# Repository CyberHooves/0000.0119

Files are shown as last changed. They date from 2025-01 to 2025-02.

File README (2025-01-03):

HAOS REDRO PN: 0000.0109

Description:
============

This is a configurable single-phase PFC booster for up to 1.2kW loads, intended for use as a front end to switchmode power supplies. The output voltage is 400V DC. An auxiliary 12V supply referenced to the negative (400V return) output is provided for powering downstream converters. This module is designed with a 35mm vertical profile to be installed within 1U rack-mounting cases.

An open-collector "power good" output is provided to indicate that the booster is switching. This should be used to disable the connected load(s) should the booster stop switching, as this will likely be due to a fault condition.
An active-low enable input is provided to disable the PFC booster in applications that require a standby mode.

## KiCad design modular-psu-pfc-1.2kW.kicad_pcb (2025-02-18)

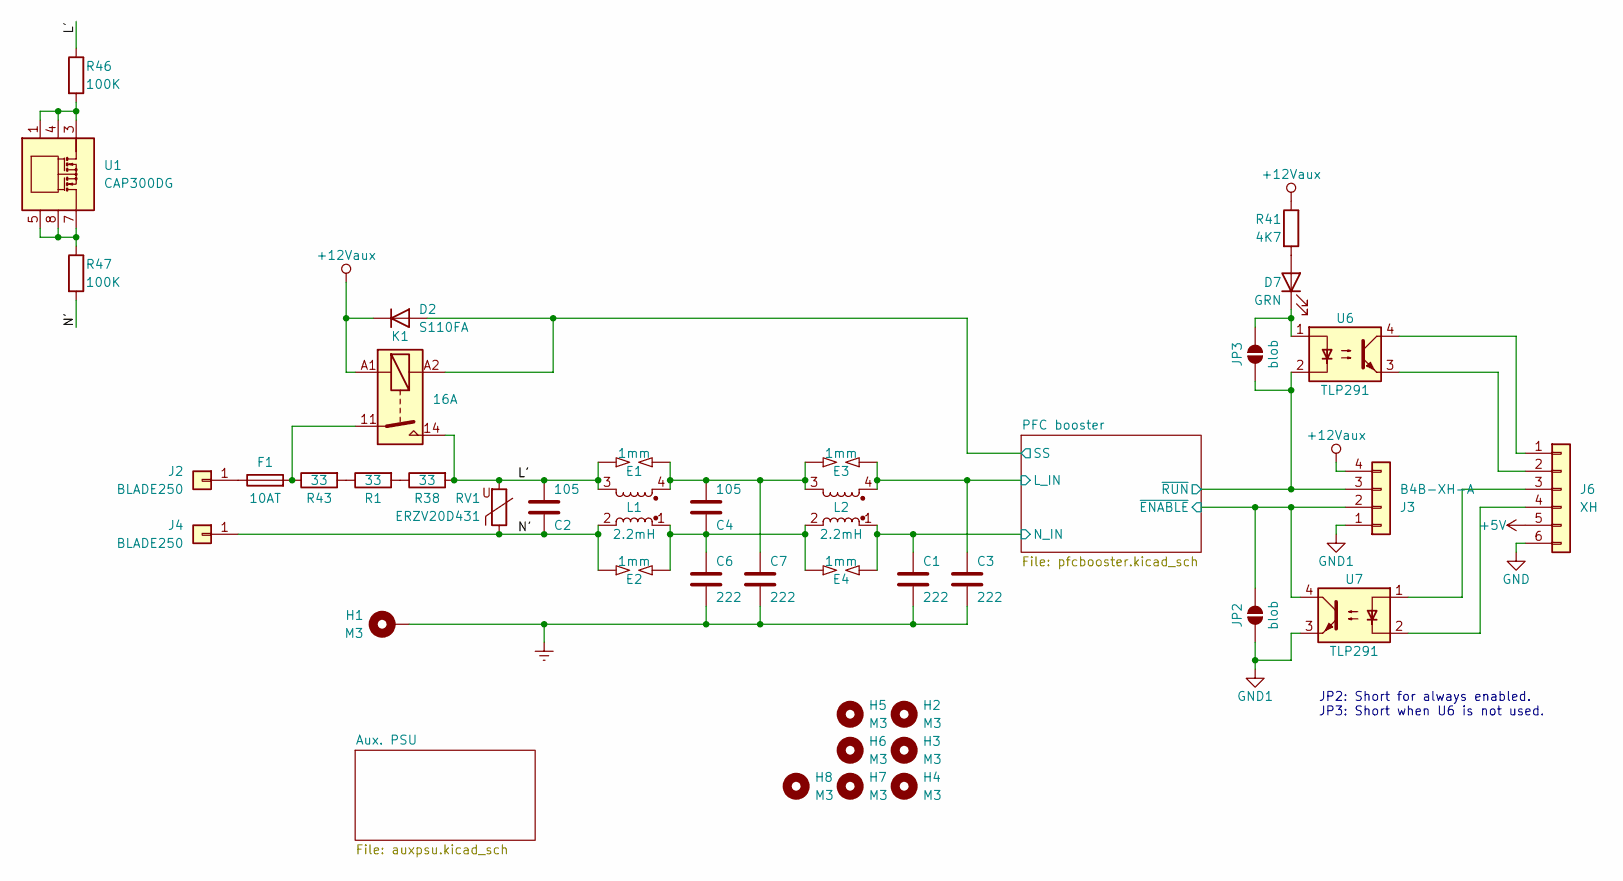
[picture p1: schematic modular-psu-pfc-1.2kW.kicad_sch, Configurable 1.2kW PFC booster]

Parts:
C1, C3, C6, C7: 222; C_Disc_D10.5mm_W5.0mm_P10.00mm
C2, C4: 105; C_Rect_L26.5mm_W11.5mm_P22.50mm_MKS4
D2: S110FA; D_SOD-123
D7: GRN; LED_D3.0mm_Clear
E1, E2, E3, E4: 1mm; SG_6MM_3SPIKE_GAP1MM
F1: 10AT; Fuseholder_Clip-6.3x32mm_Littelfuse_102071_Inline_P34.70x7.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
H1: M3; MountingHole_3.2mm_M3_Pad
H2, H3, H4, H5, H6, H7, H8: M3; MountingHole_3.2mm_M3
J2, J4: BLADE250; CON-BLADE250-VERTICAL
J3: B4B-XH-A; JST_XH_B4B-XH-AM_1x04_P2.50mm_Vertical
J6: XH; JST_XH_B6B-XH-AM_1x06_P2.50mm_Vertical
JP2, JP3: blob; SolderJumper-2_P1.3mm_Open_RoundedPad1.0x1.5mm
K1: 16A; Relay_SPST_Schrack-RT1-16A-FormA_RM5mm
L1, L2: 2.2mH; L_CommonMode_Toroid_Vertical_L30.5mm_W15.2mm_Px10.16mm_Py20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
R1, R38, R43: 33; R_Axial_DIN0617_L17.0mm_D6.0mm_P5.08mm_Vertical
R41: 4K7; R_0805_2012Metric
R46, R47: 100K; R_1210_3225Metric
RV1: ERZV20D431; RV_Disc_D21.5mm_W4.7mm_P10mm
U1: CAP300DG; SOIC-8_3.9x4.9mm_P1.27mm
U6, U7: TLP291; SOP-4_7.5x4.1mm_P2.54mm

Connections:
+5V: J6.5; also elsewhere on the board
+12Vaux: D2.1 (K), J3.4, K1.A1, R41.1; also elsewhere on the board
/L': C2.2, E1.1, K1.14, L1.3, R38.2, R46.1, RV1.2
/N': C2.1, E2.1, J4.1, L1.2, R47.2, RV1.1
/PFC booster/L_IN: C3.1, E3.2, L2.4; also elsewhere on the board
/PFC booster/N_IN: C1.1, E4.2, L2.1; also elsewhere on the board
/PFC booster/SS: D2.2 (A), K1.A2; also elsewhere on the board
/PFC booster/~ENABLE: J3.2, JP2.2 (B), U7.4; also elsewhere on the board
/PFC booster/~RUN: J3.3, JP3.1 (A), U6.2; also elsewhere on the board
Earth: C1.2, C3.2, C6.2, C7.2, H1.1
GND: J6.6; also elsewhere on the board
GND1: J3.1, JP2.1 (A), U7.3; also elsewhere on the board
unnamed: C4.1, C6.1, E2.2, E4.1, L1.1, L2.2
unnamed: C4.2, C7.1, E1.2, E3.1, L1.4, L2.3
unnamed: D7.2 (A), R41.2
unnamed: D7.1 (K), JP3.2 (B), U6.1
unnamed: F1.2, K1.11, R43.1
unnamed: F1.1, J2.1
unnamed: J6.1, U6.4
unnamed: J6.2, U6.3
unnamed: J6.3, U7.1
unnamed: J6.4, U7.2
unnamed: R1.1, R43.2
unnamed: R1.2, R38.1
unnamed: R46.2, U1.1, U1.2, U1.3, U1.4
unnamed: R47.1, U1.5, U1.6, U1.7, U1.8

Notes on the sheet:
JP2: Short for always enabled. JP3: Short when U6 is not used.

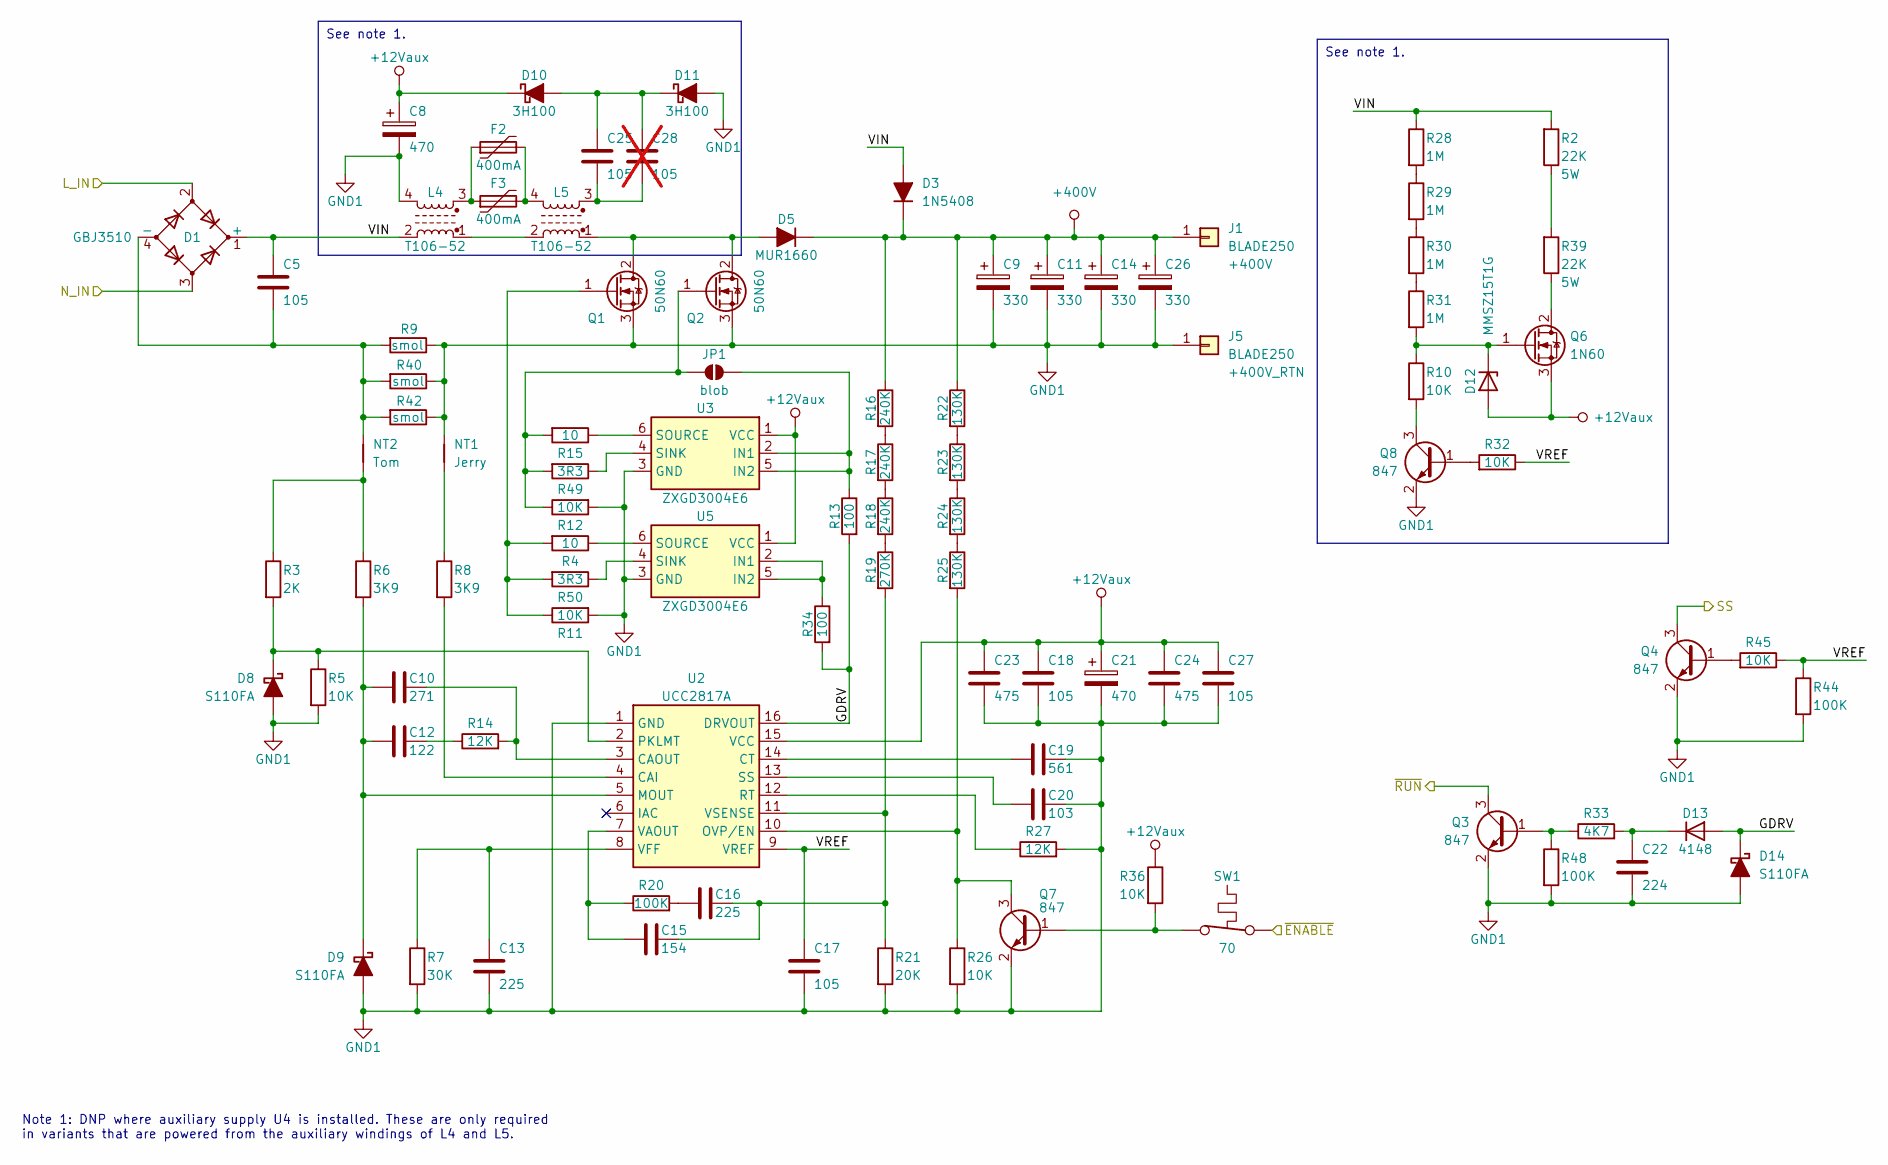
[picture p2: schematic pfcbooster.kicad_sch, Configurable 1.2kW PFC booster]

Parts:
C5: 105; C_Rect_L26.5mm_W11.5mm_P22.50mm_MKS4
C8, C21: 470; CP_Radial_D10.0mm_P5.00mm
C9, C11, C14, C26: 330; CP_Radial_D30.0mm_P10.00mm_SnapIn
C10: 271; C_0805_2012Metric
C12: 122; C_0805_2012Metric
C13, C16: 225; C_0805_2012Metric
C15: 154; C_0805_2012Metric
C17, C18, C27: 105; C_0805_2012Metric
C19: 561; C_0805_2012Metric
C20: 103; C_0805_2012Metric
C22: 224; C_0805_2012Metric
C23, C24: 475; C_1210_3225Metric
C25: 105; C_1210_3225Metric
C28: 105; C_1210_3225Metric; not fitted
D1: GBJ3510; DIODE_BRIDGE_PB_VERTICAL
D3: 1N5408; D_DO-201_P15.24mm_Horizontal
D5: MUR1660; TO-220-2_Vertical
D8, D9, D14: S110FA; D_SOD-123
D10, D11: 3H100; D_SMB
D12: MMSZ15T1G; D_SOD-123
D13: 4148; D_SOD-123
F2, F3: 400mA; Fuse_1812_4532Metric
J1, J5: BLADE250; CON-BLADE250-VERTICAL
JP1: blob; SolderJumper-2_P1.3mm_Open_RoundedPad1.0x1.5mm
L4, L5: T106-52; L_TOROID_D32_W18_4P_2
NT1: Jerry; NetTie-2_SMD_Pad0.5mm
NT2: Tom; NetTie-2_SMD_Pad0.5mm
Q1, Q2: 50N60; TO-247-3_Vertical
Q3, Q4, Q7, Q8: 847; SOT-23
Q6: 1N60; TO-252-2
R2, R39: 22K; R_Axial_DIN0617_L17.0mm_D6.0mm_P5.08mm_Vertical
R3: 2K; R_0805_2012Metric
R4, R15: 10; R_0805_2012Metric
R5, R10, R11, R12, R26, R32, R36, R45: 10K; R_0805_2012Metric
R6, R8: 3K9; R_0805_2012Metric
R7: 30K; R_0805_2012Metric
R9, R40, R42: smol; R_2512_6332Metric
R13, R34: 100; R_0805_2012Metric
R14, R27: 12K; R_0805_2012Metric
R16, R17, R18: 240K; R_0805_2012Metric
R19: 270K; R_0805_2012Metric
R20, R44, R48: 100K; R_0805_2012Metric
R21: 20K; R_0805_2012Metric
R22, R23, R24, R25: 130K; R_0805_2012Metric
R28, R29, R30, R31: 1M; R_0805_2012Metric
R33: 4K7; R_0805_2012Metric
R49, R50: 3R3; R_0805_2012Metric
SW1: 70; TO-220-2_Vertical
U2: UCC2817A; SOIC-16_3.9x9.9mm_P1.27mm
U3, U5: ZXGD3004E6; SOT-23-6

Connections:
+12Vaux: C8.1, C18.1, C21.1, C23.1, C24.1, C27.1, D10.1 (K), D12.2 (A), Q6.3 (S), R36.1, U2.15 (VCC), U3.1 (VCC), U5.1 (VCC); also elsewhere on the board
+400V: C9.1, C11.1, C14.1, C26.1, D3.1 (K), D5.1 (K), J1.1, R16.1, R22.1; also elsewhere on the board
/PFC booster/GDRV: D13.2 (A), D14.1 (K), R13.2, R34.2, U2.16 (DRVOUT)
/PFC booster/L_IN: D1.2; also elsewhere on the board
/PFC booster/N_IN: D1.3; also elsewhere on the board
/PFC booster/SS: Q4.3 (C); also elsewhere on the board
/PFC booster/VIN: C5.1, D1.1 (+), D3.2 (A), L4.2, R2.2, R28.1
/PFC booster/VREF: C17.1, R32.1, R44.1, R45.1, U2.9 (VREF)
/PFC booster/~ENABLE: SW1.1; also elsewhere on the board
/PFC booster/~RUN: Q3.3 (C); also elsewhere on the board
GND1: C8.2, C9.2, C11.2, C13.2, C14.2, C17.2, C18.2, C19.2, C20.2, C21.2, C22.2, C23.2, C24.2, C26.2, C27.2, D8.2 (A), D9.2 (A), D11.2 (A), D14.2 (A), J5.1, L4.4, NT1.2, Q1.3 (S), Q2.3 (S), Q3.2 (E), Q4.2 (E), Q7.2 (E), Q8.2 (E), R5.2, R7.2, R9.1, R11.2, R12.2, R21.2, R26.2, R27.2, R40.1, R42.1, R44.2, R48.2, U2.1 (GND), U3.3 (GND), U5.3 (GND); also elsewhere on the board
unnamed: C12.2, R14.1
unnamed: C16.1, R20.2
unnamed: C25.2, C28.2, L5.3
unnamed: C5.2, D1.4 (-), NT2.2, R9.2, R40.2, R42.2
unnamed: D5.2 (A), L5.1, Q1.2 (D), Q2.2 (D)
unnamed: D8.1 (K), R3.2, R5.1, U2.2 (PKLMT)
unnamed: C10.1, C12.1, D9.1 (K), R6.2, U2.5 (MOUT)
unnamed: C25.1, C28.1, D10.2 (A), D11.1 (K)
unnamed: D12.1 (K), Q6.1 (G), R10.1, R31.2
unnamed: C22.1, D13.1 (K), R33.2
unnamed: F2.1, F3.1, L4.3
unnamed: F2.2, F3.2, L5.4
unnamed: JP1.1 (A), Q2.1 (G), R12.1, R15.2, R49.2
unnamed: JP1.2 (B), R13.1, U3.2 (IN1), U3.5 (IN2)
unnamed: L4.1, L5.2
unnamed: NT1.1, R8.1
unnamed: NT2.1, R3.1, R6.1
unnamed: Q1.1 (G), R4.2, R11.1, R50.2
unnamed: Q3.1 (B), R33.1, R48.1
unnamed: Q4.1 (B), R45.2
unnamed: Q6.2 (D), R39.1
unnamed: Q7.1 (B), R36.2, SW1.2
unnamed: Q7.3 (C), R25.2, R26.1, U2.10 (OVP/EN)
unnamed: Q8.1 (B), R32.2
unnamed: Q8.3 (C), R10.2
unnamed: R2.1, R39.2
unnamed: R16.2, R17.1
unnamed: R17.2, R18.1
unnamed: R18.2, R19.1
unnamed: R22.2, R23.1
unnamed: R23.2, R24.1
unnamed: R24.2, R25.1
unnamed: R28.2, R29.1
unnamed: R29.2, R30.1
unnamed: R30.2, R31.1
unnamed: R8.2, U2.4 (CAI)
unnamed: C10.2, R14.2, U2.3 (CAOUT)
unnamed: C19.1, U2.14 (CT)
unnamed: R27.1, U2.12 (RT)
unnamed: C20.1, U2.13 (SS)
unnamed: C15.1, R20.1, U2.7 (VAOUT)
unnamed: C13.1, R7.1, U2.8 (VFF)
unnamed: C15.2, C16.2, R19.2, R21.1, U2.11 (VSENSE)
unnamed: R49.1, U3.4 (SINK)
unnamed: R15.1, U3.6 (SOURCE)
unnamed: R34.1, U5.2 (IN1), U5.5 (IN2)
unnamed: R50.1, U5.4 (SINK)
unnamed: R4.1, U5.6 (SOURCE)

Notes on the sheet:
See note 1.
Note 1: DNP where auxiliary supply U4 is installed. These are only required in variants that are powered from the auxiliary windings of L4 and L5.

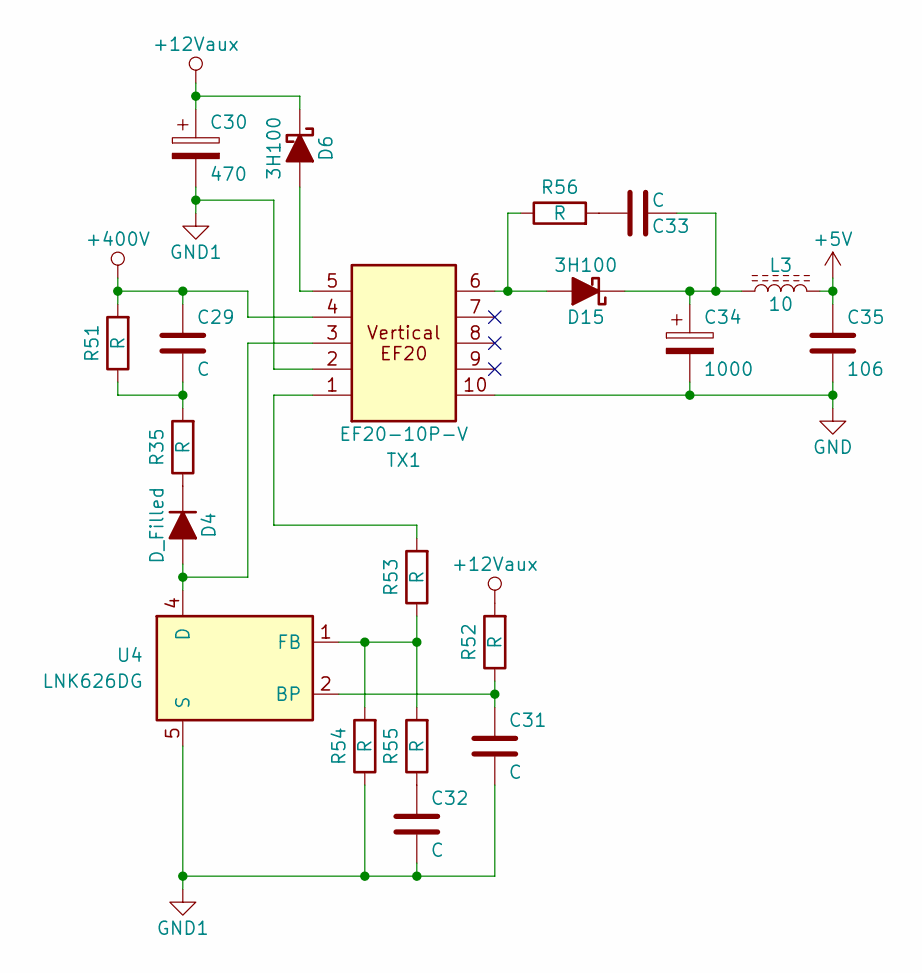
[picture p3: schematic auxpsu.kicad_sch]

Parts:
C29: C; C_1206_3216Metric
C30: 470; CP_Radial_D10.0mm_P5.00mm
C31, C32, C33: C; C_0805_2012Metric
C34: 1000; CP_Radial_D10.0mm_P5.00mm
C35: 106; C_1210_3225Metric
D4: D_Filled; D_SOD-123
D6, D15: 3H100; D_SMB
L3: 10; INDUCTOR_SMD_4x4
R35, R52, R53, R54, R55, R56: R; R_0805_2012Metric
R51: R; R_1206_3216Metric
TX1: EF20-10P-V; TRANSFORMER-EF20-10P-V
U4: LNK626DG; PowerIntegrations_SO-8C

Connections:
+5V: C35.1, L3.2; also elsewhere on the board
+12Vaux: C30.1, D6.1 (K), R52.2; also elsewhere on the board
+400V: C29.1, R51.2, TX1.4; also elsewhere on the board
GND: C34.2, C35.2, TX1.10; also elsewhere on the board
GND1: C30.2, C31.2, C32.2, R54.1, TX1.2, U4.5 (S), U4.6 (S), U4.7 (S), U4.8 (S); also elsewhere on the board
unnamed: C29.2, R35.2, R51.1
unnamed: C32.1, R55.1
unnamed: C33.1, R56.2
unnamed: D4.2 (A), TX1.3, U4.4 (D)
unnamed: D4.1 (K), R35.1
unnamed: D6.2 (A), TX1.5
unnamed: D15.2 (A), R56.1, TX1.6
unnamed: C33.2, C34.1, D15.1 (K), L3.1
unnamed: R53.2, TX1.1
unnamed: C31.1, R52.1, U4.2 (BP)
unnamed: R53.1, R54.2, R55.2, U4.1 (FB)

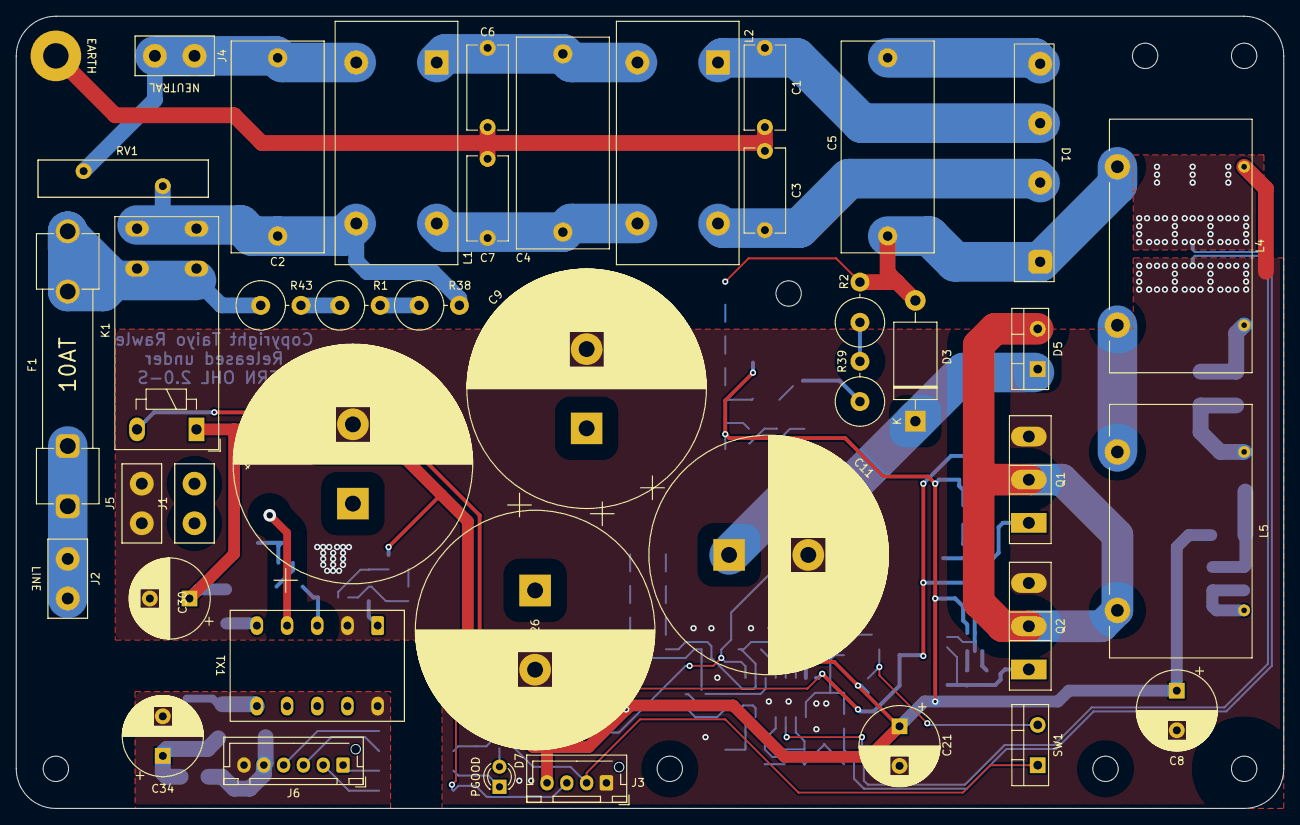
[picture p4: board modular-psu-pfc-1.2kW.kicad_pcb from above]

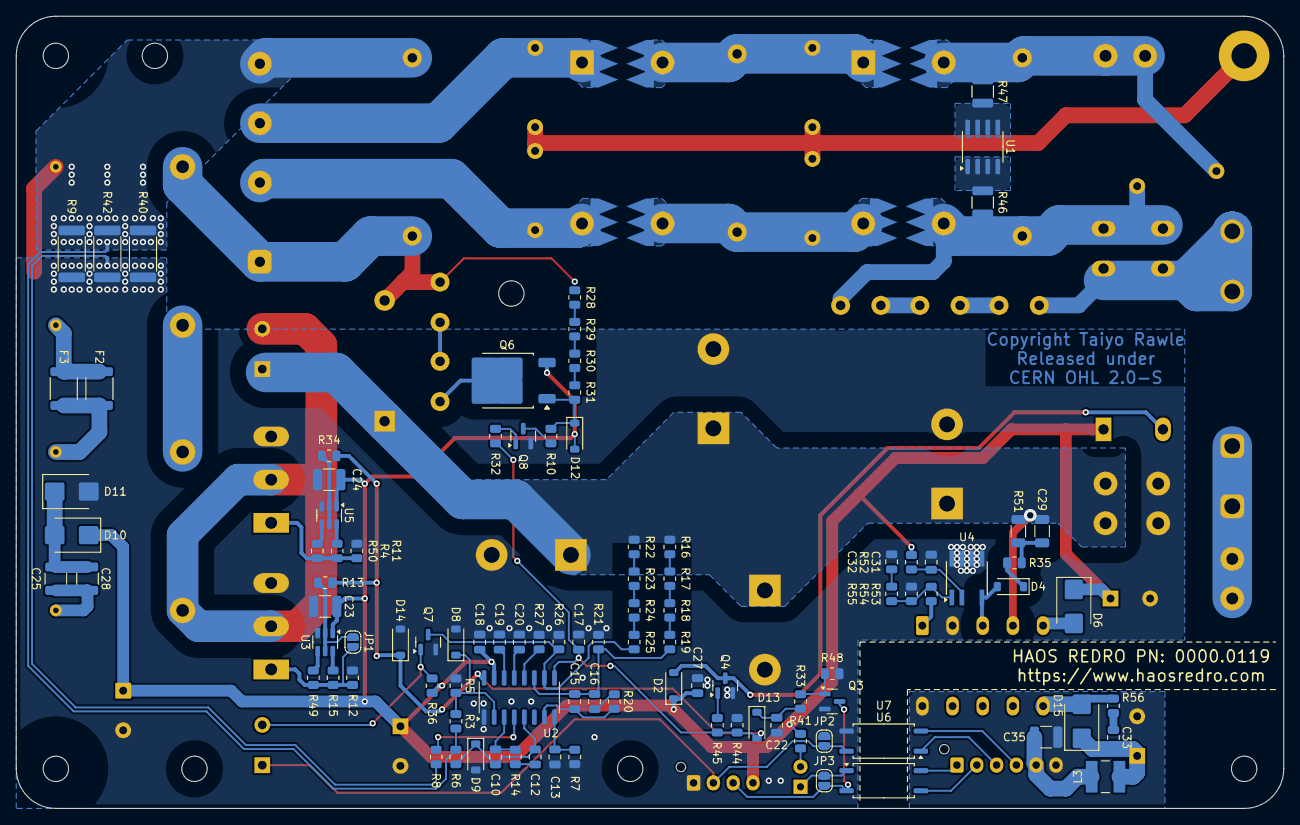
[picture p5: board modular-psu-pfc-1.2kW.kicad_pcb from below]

Board: 2 copper layers, 160.0 x 100.0 mm, 154 parts (105 on the bottom side), 89 nets.

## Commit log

2025-01-03 Updated design. Heatink fasteners now accessible!
    [auxpsu.kicad_sch, inputfilter.kicad_sch, modular-psu-pfc-1.2kW.kicad_pcb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]
2025-02-18 Schematic & PCB updated.
    [auxpsu.kicad_sch, modular-psu-pfc-1.2kW.kicad_pcb, modular-psu-pfc-1.2kW.kicad_sch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]

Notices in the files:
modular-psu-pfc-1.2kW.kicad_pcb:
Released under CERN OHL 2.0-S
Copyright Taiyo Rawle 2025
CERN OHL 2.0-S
